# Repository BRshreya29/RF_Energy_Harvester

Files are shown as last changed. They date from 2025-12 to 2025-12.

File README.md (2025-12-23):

# RF Energy Harvester – 2.4 GHz

This repository contains the complete design, fabrication, and testing files for a **2.4 GHz RF Energy Harvester**, including antenna design, rectifier circuit design, CST simulations, KiCAD PCB layouts, fabrication outputs, and VNA measurement results.

The harvester is designed for low-power IoT applications and captures RF energy in the 2.4 GHz ISM band.  
The project includes **antenna simulation + PCB**, **rectifier circuit + PCB**, and full hardware testing.

---

## 1. Antenna Design (CST Studio)

The antenna was designed and optimized in **CST Studio** for the 2.45 GHz ISM band.

### Key Features  
- Designed for 2.4–2.5 GHz bandwidth  
- Simulated S11 < –22 dB at resonance  
- Fabricated as a **double-layer PCB**  
- Measured using **R60 Vector Network Analyzer**

### Antenna Images  
#### CST Antenna Model  
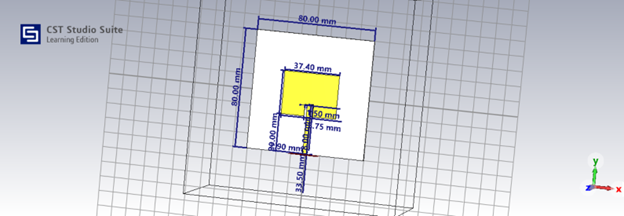
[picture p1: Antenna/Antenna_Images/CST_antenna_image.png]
CST Antenna


#### CST S11 Simulation  
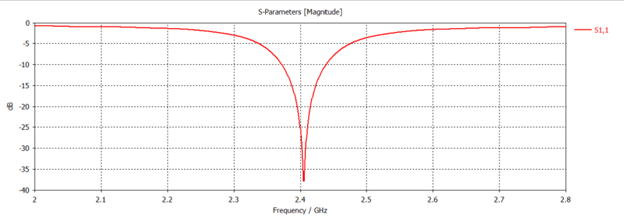
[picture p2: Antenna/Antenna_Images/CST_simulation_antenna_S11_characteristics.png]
CST S11


#### Fabricated Antenna  
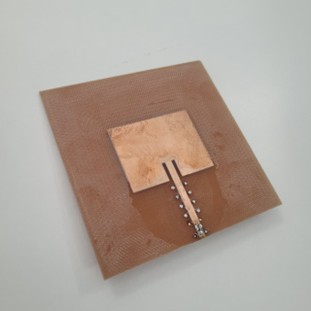
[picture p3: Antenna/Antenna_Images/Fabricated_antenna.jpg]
Fabricated Antenna


#### PCB Layout  
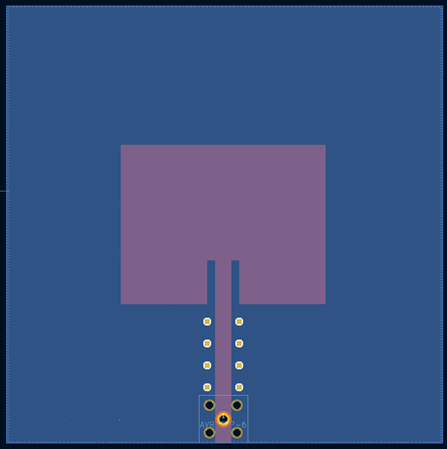
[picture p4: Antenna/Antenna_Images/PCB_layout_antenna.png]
PCB Layout


#### VNA Measurement (Hardware S11)  
Achieved a **return loss of –22.209 dB at 2.48 GHz**, which is excellent and closely matches simulations.

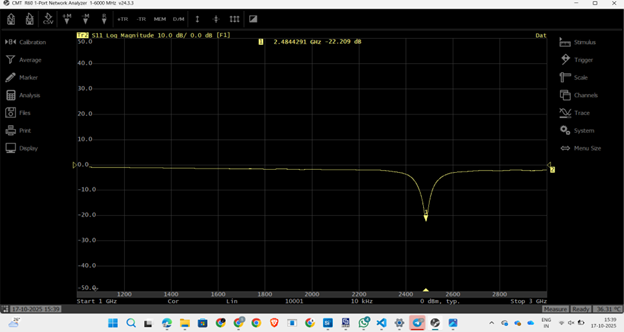
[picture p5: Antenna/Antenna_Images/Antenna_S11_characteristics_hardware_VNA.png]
VNA S11


---

## 2. Antenna PCB Files (KiCAD)

The antenna PCB was fully designed in **KiCAD**, fabricated in the lab, and assembled manually.

### PCB Highlights  
- **Double-layer PCB** for RF stability  
- **Vias added** for grounding and performance  
- **Custom SMA connector footprint** created because KiCAD did not have the required part  
- SMA footprint file:
```
Antenna/Antenna_PCB_files/Library/SMAmale.kicad_mod
```

### PCB Files  
```
Antenna/Antenna_PCB_files/KiCAD pcb files
Antenna/Antenna_PCB_files/antenna_gerber_files.zip
Antenna/Antenna_PCB_files/Library/SMAmale.kicad_mod
```

---

## 3. Rectifier Circuit (ADS + KiCAD)

The rectifier circuit uses a multi-stage RF-to-DC rectification approach.  
The circuit was simulated in **ADS**, then designed as a **double-layer PCB** in KiCAD.

### Circuit Images  
#### Schematic  
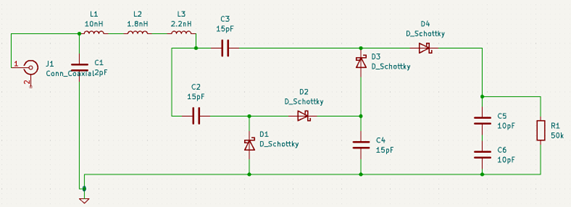
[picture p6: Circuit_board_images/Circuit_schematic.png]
Circuit Schematic


#### PCB Layout  
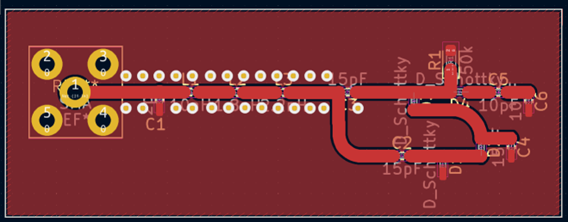
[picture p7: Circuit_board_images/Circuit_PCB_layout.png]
Circuit Layout


#### Fabricated Rectifier Board  
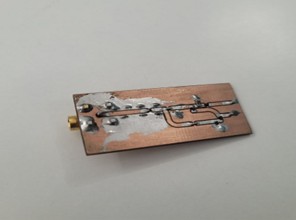
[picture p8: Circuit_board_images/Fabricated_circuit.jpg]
Fabricated Circuit


### PCB Files  
```
Circuit_board_PCB_files/KiCAD pcb files
Circuit_board_PCB_files/gerber files (2).zip
Circuit_board_PCB_files/Library/SMA.kicad_mod
```

### PCB Highlights  
- Designed in **KiCAD**  
- **RF-friendly routing** with short traces  
- **Ground vias stitched** for stability  
- **Custom SMA connector footprint** added:
```
Circuit_board_PCB_files/Library/SMA.kicad_mod
```

---

## 4. Repository Structure

```
RF_Energy_Harvester_2.4GHz/
│
├── README.md
│
├── Antenna/
│   ├── Antenna_Images/
│   │   ├── Multiple_images
│   ├── Antenna_PCB_files/
│   │   ├── KiCAD_PCB_files
|   |   ├── gerber_files.zip
│   │   └── Library/SMAmale.kicad_mod
│   └── CST_Files/antenna3.cst
│
├── Cicuit_board_images/
│   ├── Circuit_PCB_layout.png
│   ├── Circuit_schematic.png
│   └── Fabricated_circuit.jpg
│
├── Circuit_board_PCB_files/
│   │   ├── KiCAD_PCB_files
│   ├── gerber files (2).zip
│   └── Library/SMA.kicad_mod
│
└── RF_Energy_Harvester_Documentation.pdf
```

---

## 5. Documentation

Complete design report, analysis, S11 results, and rectifier circuit details:

```
RF_Energy_Harvester_Documentation.pdf
```

---

## Summary

This repository contains:

- CST antenna simulation  
- KiCAD PCB design for antenna and rectifier  
- ADS circuit simulation  
- Fabricated double-layer PCBs  
- VNA-measured return loss of **–22.209 dB at 2.48 GHz**  
- Custom SMA footprints  
- Complete fabrication-ready Gerber files  

The project successfully demonstrates a working **2.4 GHz RF Energy Harvester** with close agreement between simulation and hardware of antenna only.

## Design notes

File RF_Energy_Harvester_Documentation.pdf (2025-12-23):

# Radio Frequency Energy Harvesting

A wide spectrum of radio frequency signals are present in atmosphere, the idea here is to explore, research, simulate and test the concept of harvesting energy from these radio frequency signals.

RF Energy harvestable bands:

Source | Representative Frequency Bands
AM Radio | 530–1,700kHz
FM Radio | 88–108MHz
TV Broadcast/DTV | 550–600MHz
GSM-900 | 850–910MHz
GSM-1800 | 1,850–1,900MHz
WiFi/ISM | 2,400–2,450MHz, 5,150–5,825MHz
BLE (Bluetooth Low Energy) | 2,402–2,480MHz
UMTS/LTE | 2,150–2,200MHz, 700–800MHz
UWB | 3,100–10,600MHz
WLAN | 3,100–4,400MHz
C-Band | 4,400–5,000MHz

Design Strategy for RF Energy Harvester:

The choice of design of an RF energy harvester should be guided by three key performance factors: frequency band, output voltage, and power conversion efficiency (PCE). The process begins with selecting the appropriate frequency bands from which ambient RF energy will be harvested. This selection is based on the availability and strength of RF signals in the environment, such as GSM-900, GSM-1800, LTE, Wi-Fi, and DTV bands. Once the bands are identified, the next step involves evaluating whether the harvester should be designed as a narrowband, broadband, or wideband system. This decision depends on the number of bands targeted and the trade-offs between size, efficiency, and complexity. A practical approach is to first design and test individual harvesters for each selected band, analyzing their output voltage and PCE. Based on these results, a multiband or unified design can be developed to optimize performance across multiple frequency bands. This staged methodology ensures that the final harvester design is both efficient and tailored to the ambient RF environment.

Research paper’s with various designs were explored and three main focus areas were decided.

1. 900MHz Frequency band
2. 2.4GHz Frequency band

### 3. Broadband based design

The above frequency designs were explored from research papers.

Frequency band(s) | Paper | Link
2.4–2.45 GHz ISM | Development of 2400–2450 MHz Frequency Band RF Energy Harvesting System for Portable Gadgets and Low-Power Devices (authors include N. U. Khan) | National Library of Medicine (full text): https://pmc.ncbi.nlm.nih.gov/articles/PMC11125279/
2.1 GHz and 5.8 GHz Dual-band | A dual band rectifying antenna for RF energy harvesting (Neeta Singh et al., 2018) | Springer (record): https://dl.acm.org/doi/abs/10.1007/s10825-018-1241-6
GSM-900 downlink (~935–960 MHz) | DESIGN OF RF ENERGY HARVESTING SYSTEM FOR ENERGIZING LOW POWER DEVICES (N. M. Din et al., 2012) | PIER PDF: https://www.jpier.org/ac_api/download.php?id=120720 02
800 MHz–2.5 GHz (CDMA, GSM900, GSM1800, 3G) | Broadband RF Energy Harvesting System covering CDMA, GSM900, GSM1800, 3G Bands with Inherent Impedance Matching (Arrawatia, Shojaei Baghini, Girish Kumar) | Semantic Scholar record: https://www.semanticscholar.org/paper/Broadband-RF-energy-harvesting-system-covering-3G-Arrawatia-Baghini/d7eb30f01bc19df674a0b9f60da2d56e98769d2c
1.8–2.5 GHz broadband | A High-Efficiency Broadband Rectenna for Ambient Wireless Energy Harvesting (Chaoyun Song, Yi Huang, et al., IEEE TAP 2015) | University of Liverpool repository (PDF link inside): https://livrepository.liverpool.ac.uk/3005519/
2.4 GHz and 5 GHz (ISM/WLAN) | Dual Band Rectenna for Electromagnetic Energy Harvesting at 2.4 GHz and 5 GHz Frequencies (L. Prashad, H. C. Mohanta, A. J. A. Al‑Gburi, 2024) | PIER B article page: https://www.jpier.org/issues/volume.html?paper=24072 102 and PDF: https://www.jpier.org/ac_api/download.php?id=240721 02

Design’s chosen to work on:

### 1. RF Energy Harvesting - Design for GSM-900 frequency band

Antenna Specifications: Thickness of substrate 1.6mm, the thickness of copper 0.035mm, the dielectric constant 3.9, and the loss tangent 0.01.

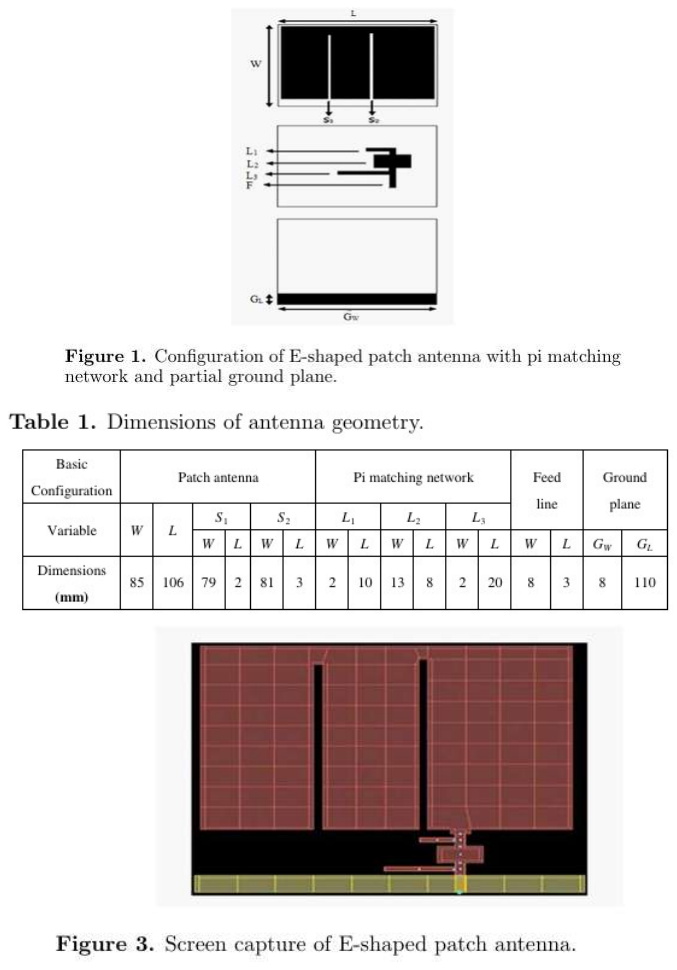
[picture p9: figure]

Impedance Matching and Rectifying Circuit:

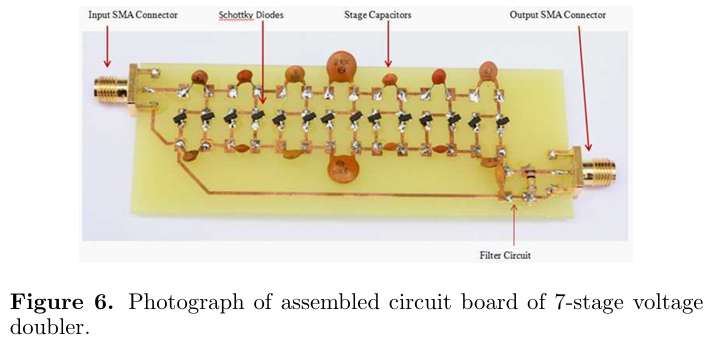
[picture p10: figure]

Components:

Description | Value
Schottky Diode | HSMS-2850
Capacitance | -
Load Resistance | -

### 2. RF Energy Harvesting - Design for 2.4GHz frequency

Antenna Specifications:
- Antenna - a rectangular metallic patch which is placed on the top of another metallic sheet called ground plan.
- Substrate - FR-4, whose dielectric constant is 4.3 A patch made up of copper and a substrate of FR-4 sheet having a thickness of 1.6 mm.

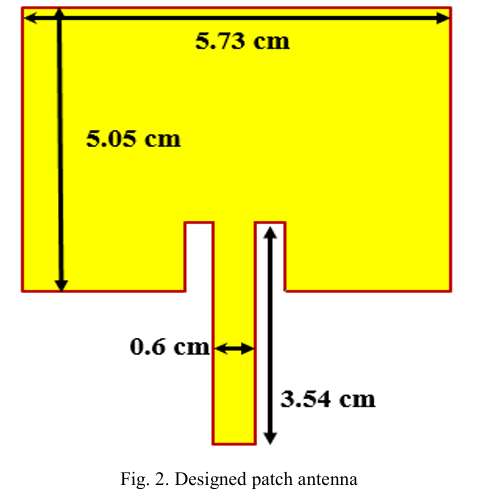
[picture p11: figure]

Impedance Matching and Rectifying circuit:

Components:

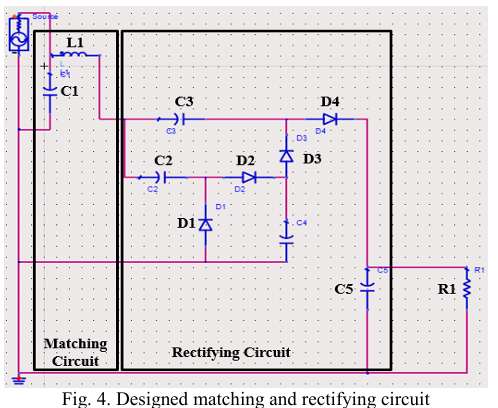
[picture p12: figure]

Description | Value
Matching Inductor L1 | 14 nH
Matching Capacitor C1 | 2pF
Rectifier Capacitor C2 | 15pF
Rectifier Capacitor C3 | 15pF
Rectifier Capacitor C4 | 15pF
Load Capacitor C5 | 5pF
Load Resistor R1 | 50kΩ
Diode | HSMS2850

### 3. RF Energy Harvesting - Design for Broadband frequency range 800MHz to 2.5GHz

Antenna Specifications: The antenna is designed on 1.6mm thick FR4 substrate (r =4.4, tan = 0.02).

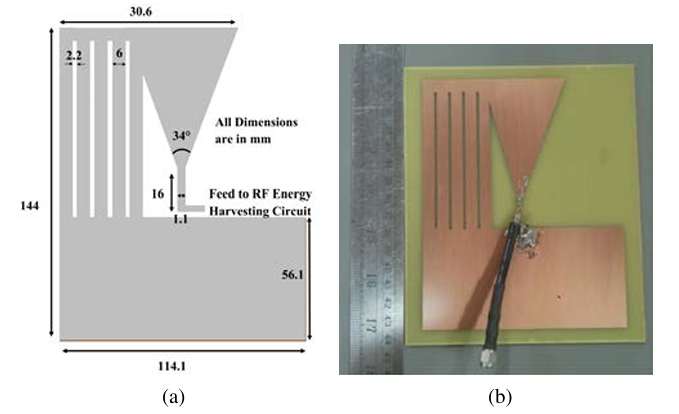
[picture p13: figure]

Impedance Matching and Rectifying circuit:

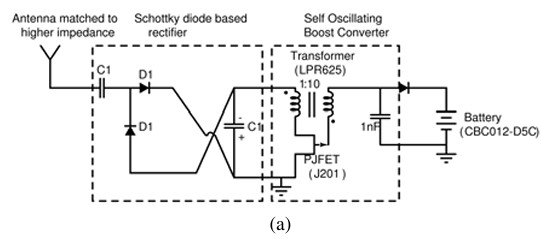
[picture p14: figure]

Components:

Description | Value
Matching capacitance C1 | -
Diode D1 | Schottky Diode
Boost circuit capacitance | 1nF
PJFET | J201

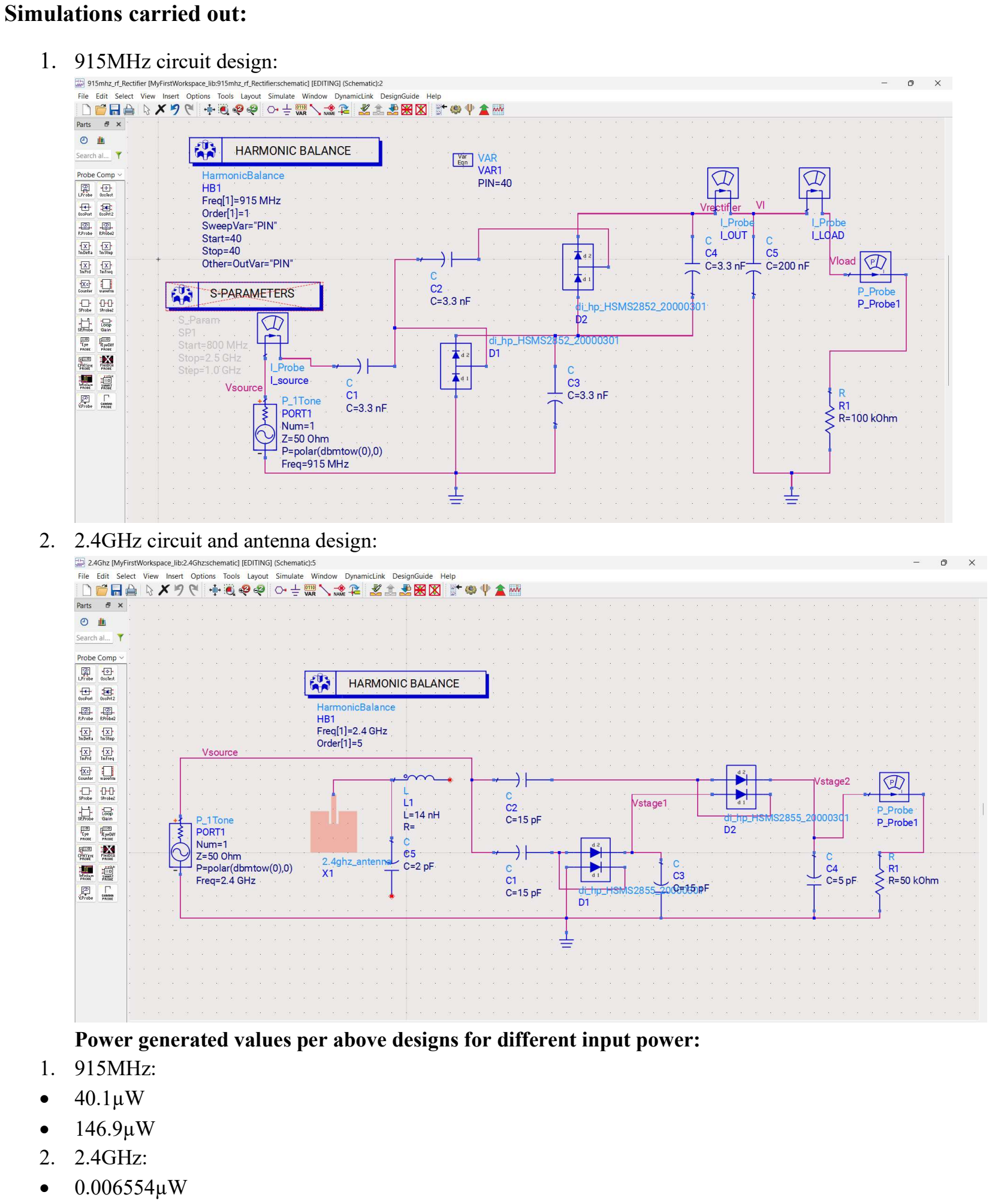
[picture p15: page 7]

Simulations carried out:

1. 915MHz circuit design:
2. 2.4GHz circuit and antenna design:

Power generated values per above designs for different input power:
1. 915MHz:
- 40.1µW
- 146.9µW
2. 2.4GHz:
- 0.006554µW

Power output values seen as mentioned in research papers:

Frequency Band | Paper Name | Max Power Output (measured) | Max Voltage Output (measured)
2400–2450 MHz ISM | Development of 2400–2450 MHz Frequency Band RF Energy Harvesting System for Portable Gadgets [Nasir Ullah Khan] | 4.60 µW (lab), 0.47 nW (WiFi field) | 5.2 V DC (lab), 1.3 V DC (field)
935–960 MHz GSM-900 | DESIGN OF RF ENERGY HARVESTING SYSTEM FOR ENERGIZING LOW POWER DEVICES [Din et al.] | 21.67 µW @ −16.64 dBm (cell tower, 50m) | 2.9 V DC (field, 50m tower), 5 V DC (lab)
800–2500 MHz (CDMA, GSM900, GSM1800, 3G) | Broadband RF Energy Harvesting System covering CDMA, GSM900, GSM1800, 3G Bands [Arrawatia, Shojaei Baghini, Kumar] | ~10–40 µW (typical, various bands) | 1–5 V (varies by band and input, bench/field)
2.1 GHz, 5.8 GHz | A dual band rectifying antenna for RF energy harvesting [Neeta Singh et al.] | 1.26 mW @ 2.4 GHz, 1.82 mW @ 5.8 GHz (sim, −3 dBm) | 2.2 V DC (sim/bench)
1.8–2.5 GHz broadband | A High-Efficiency Broadband Rectenna for Ambient Wireless Energy Harvesting [Chaoyun Song et al.] | 55% RF-DC efficiency @ −10 dBm (−35 dBm sensitivity, output power ~6.3 µW, lab) | ~1.4 V DC @ −10 dBm input (lab)
2.4 GHz & 5 GHz | Dual Band Rectenna for Electromagnetic Energy Harvesting at 2.4 GHz and 5 GHz [Prashad, Mohanta, Al-Gburi] | 315 µW @ 2.4 GHz (sim/bench); 170 µW @ 5 GHz (sim/bench) | ~1.7 V DC @ 2.4 GHz (sim)

Design Implementation in Lab:

With the idea to implement the concept and verify the power output, voltage values, the 2400–2450 MHz ISM band RF energy harvesting system from the paper 'Development of 2400–2450 MHz Frequency Band RF Energy Harvesting System for Portable Gadgets' by Nasir Ullah Khan was chosen. In the lab, the antenna design and circuit layout have been carried out according after simulations and optimization of antenna in CST Studio software for antenna. PCB layout was designed in KiCAD.

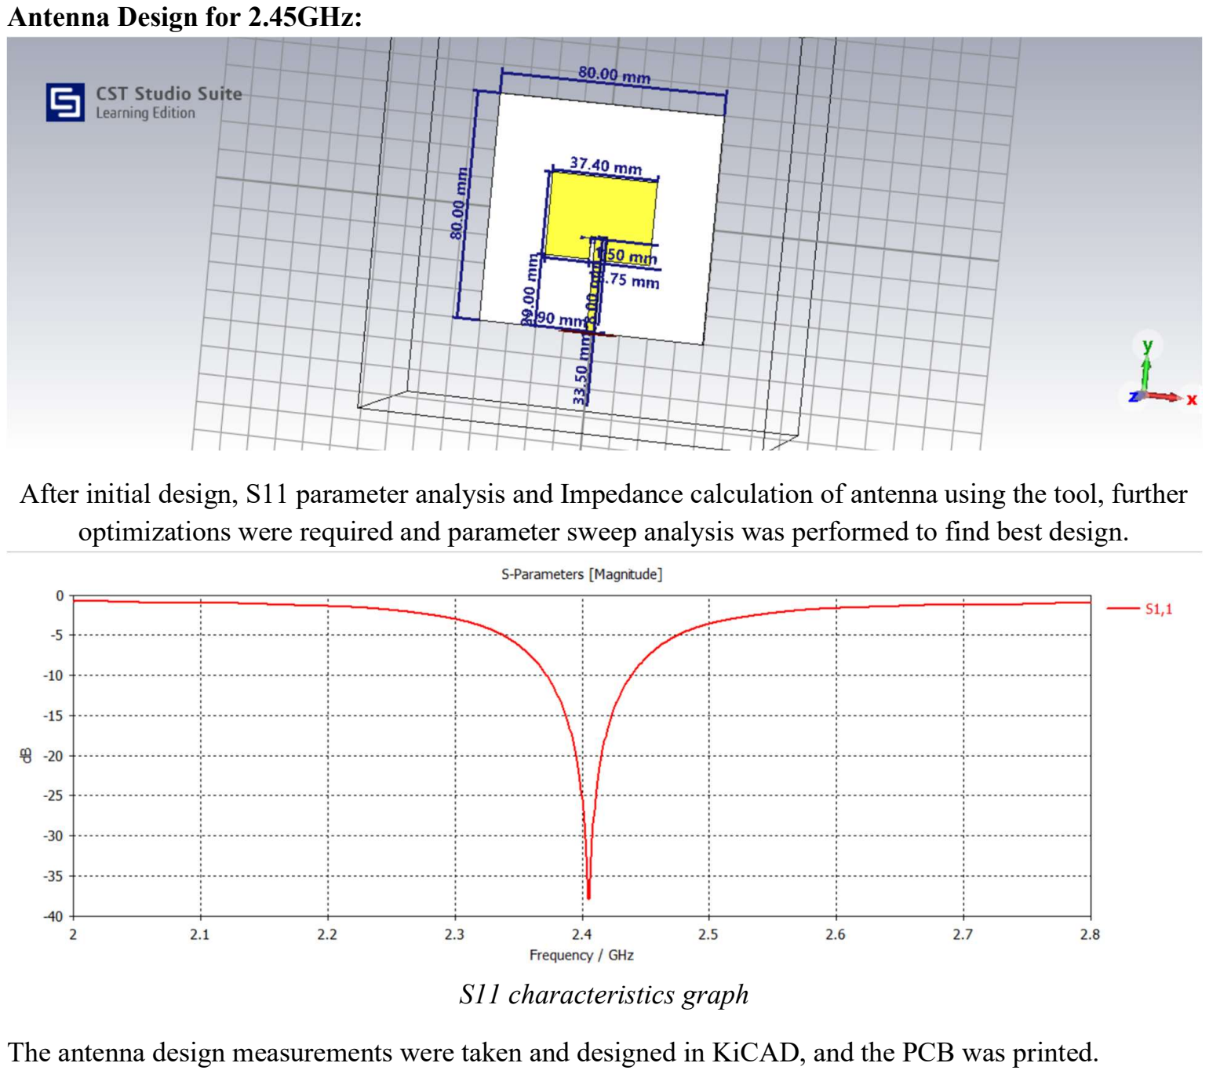
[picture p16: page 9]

Antenna Design for 2.45GHz:

After initial design, S11 parameter analysis and Impedance calculation of antenna using the tool, further optimizations were required and parameter sweep analysis was performed to find best design.

S11 characteristics graph

The antenna design measurements were taken and designed in KiCAD, and the PCB was printed.

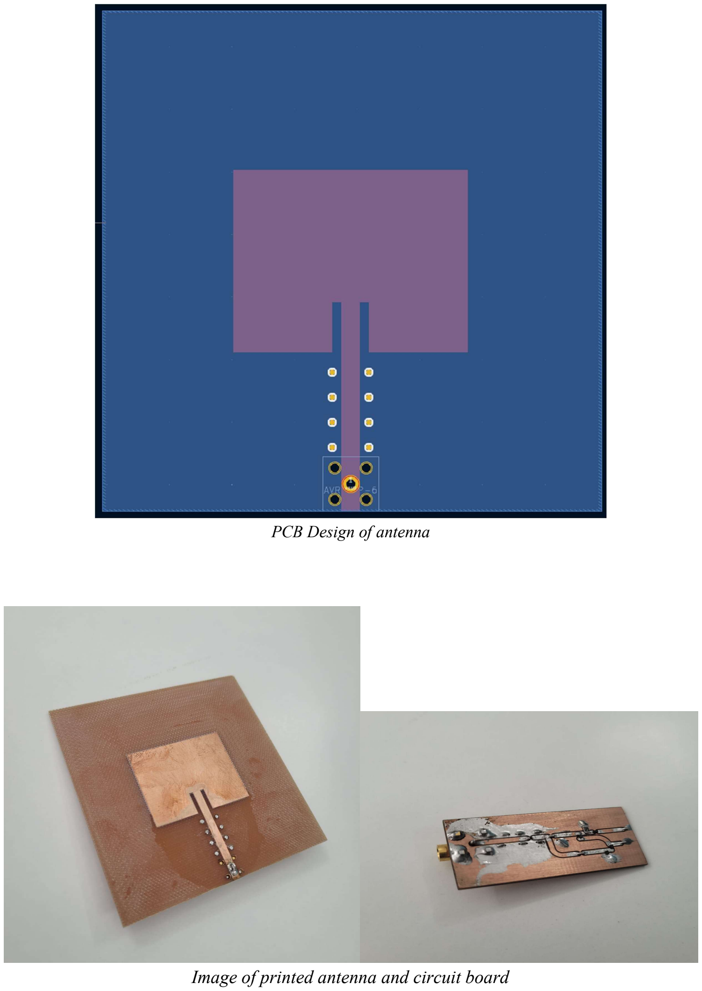
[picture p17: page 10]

PCB Design of antenna

Image of printed antenna and circuit board

A Vector Network Analyzer was used to find the performance characteristics i.e, the return loss graph across a range of frequencies. RVNA software and R-60 VNA was used. The output graph from this analysis is shown below. We can see that the antenna is well designed for the 2.48GHz point with a return loss of -22.209 dB.

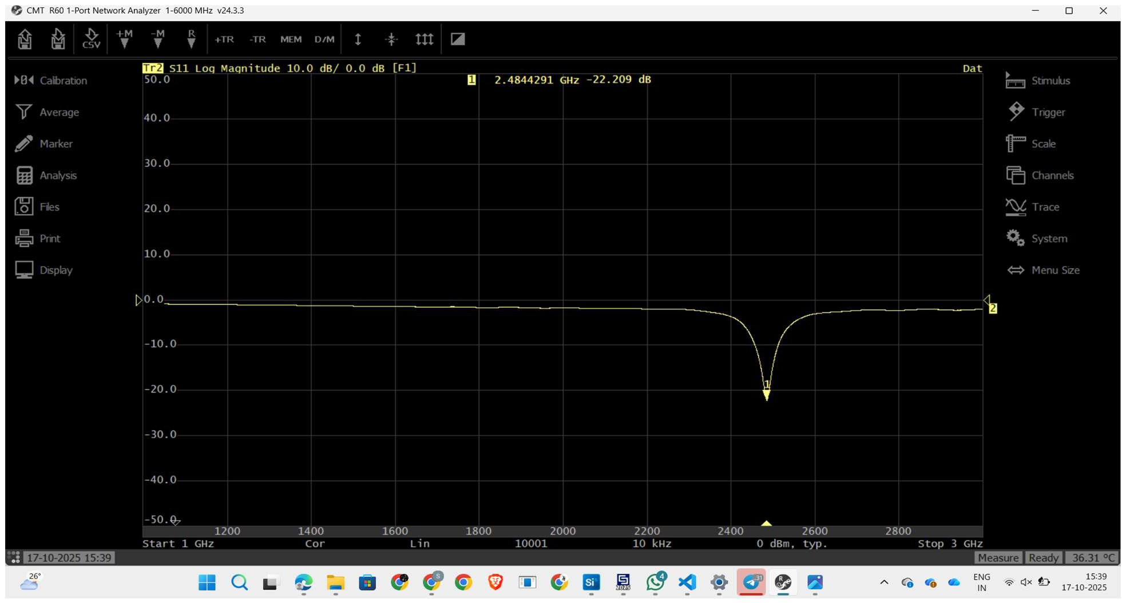
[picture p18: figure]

This antenna has a return loss of –10.042 dB at 2.45GHz and a return loss of –10.395 dB at 2.5GHz. Thus making the antenna best suitable for Wi-Fi signals energy harvesting.

Circuit Layout:

Circuit layout in KiCAD modifications based on components available. HSMS 2850 diode was out of production thus with similar characteristics and recent research papers SMS 7621 diode was chosen and replaced in design.

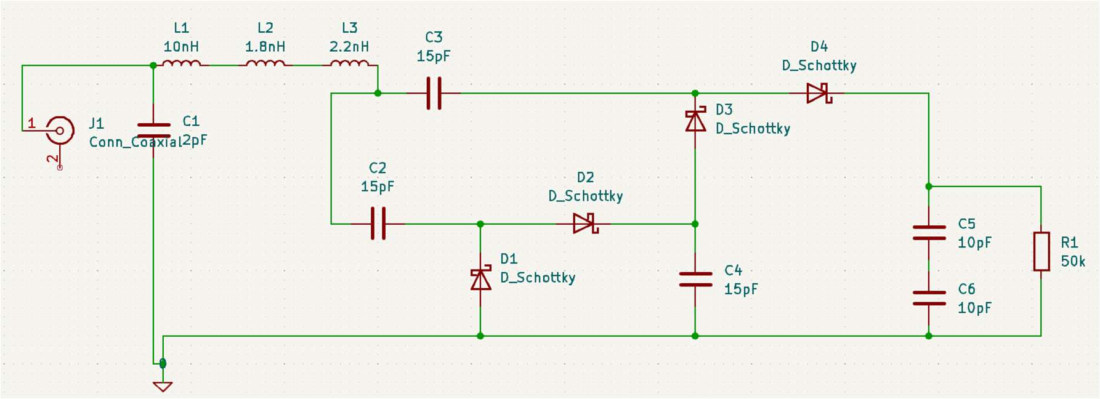
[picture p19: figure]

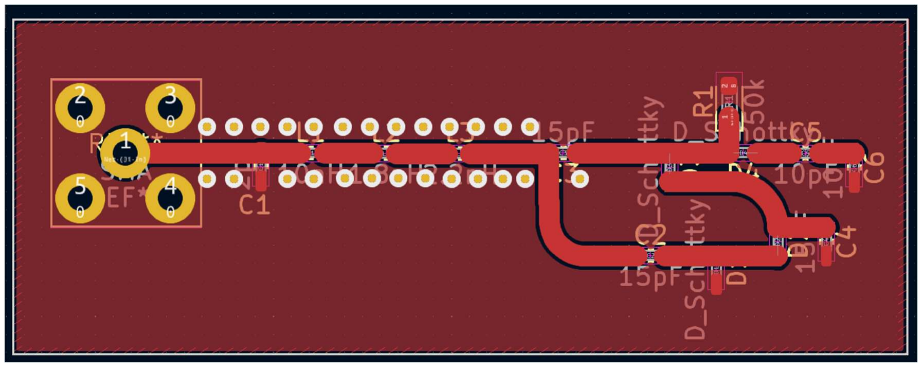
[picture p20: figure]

Antenna design and verification are complete. Testing of this circuit with the antenna together by producing Wi-Fi signals using a Wi-Fi board was in process.

Observations:

1. Antenna is working good with return loss shown of –22.209 dB at 2.48GHz.
2. Rectifying circuit is directly connected to antenna, impedance matching is not implemented at this stage.
3. Output voltage for this configuration across resistor should be ~300mV which is not seen in test, further debugging and adding of impedance matching circuit is required. Debugging steps involve – figure out tool/method to measure power present in ambient environment.
- add impedance matching circuit.
- simulations to include output at each point after signal is received at antenna, post impedance matching circuit point, rectifier output at load.

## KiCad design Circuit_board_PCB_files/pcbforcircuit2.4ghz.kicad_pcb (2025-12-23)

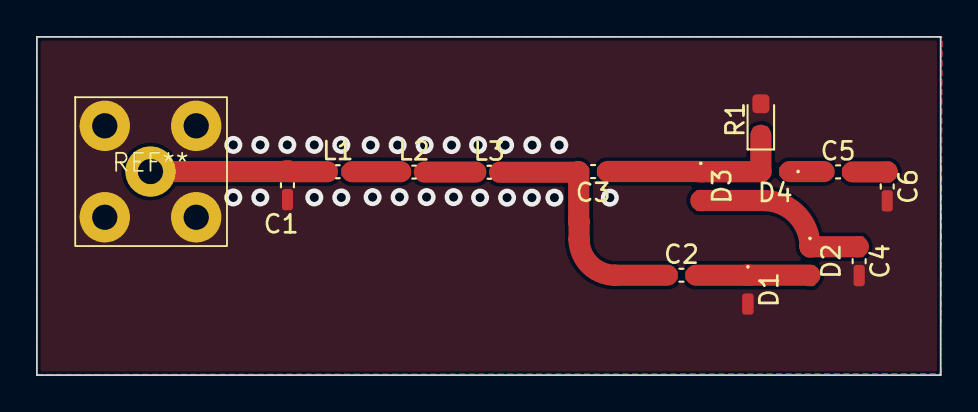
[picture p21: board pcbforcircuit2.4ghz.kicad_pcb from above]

Board: 2 copper layers, 50.2 x 18.8 mm, 14 parts (0 on the bottom side), 7 nets.

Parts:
C1: 2pF; C_0402_1005Metric_Pad0.74x0.62mm_HandSolder
C2, C3, C4: 15pF; C_0402_1005Metric_Pad0.74x0.62mm_HandSolder
C5, C6: 10pF; C_0402_1005Metric_Pad0.74x0.62mm_HandSolder
D1, D2, D3, D4: D_Schottky; D_0402_1005Metric_Pad0.77x0.64mm_HandSolder
L1: 10nH; L_0402_1005Metric_Pad0.77x0.64mm_HandSolder
L2: 1.8nH; L_0402_1005Metric_Pad0.77x0.64mm_HandSolder
L3: 2.2nH; L_0402_1005Metric_Pad0.77x0.64mm_HandSolder
R1: 50k; D_0603_1608Metric_Pad1.05x0.95mm_HandSolder

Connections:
0: C1.2, C4.2, C6.2, D1.2 (A), R1.2
unnamed: C2.1, C3.2, L3.2
unnamed: C5.2, C6.1
unnamed: C2.2, C3.1, C4.1, D1.1 (K), D2.1 (K), D2.2 (A), D3.1 (K), D3.2 (A), D4.1 (K), D4.2 (A), R1.1
unnamed: C1.1, L1.1
unnamed: L1.2, L2.1
unnamed: L2.2, L3.1
